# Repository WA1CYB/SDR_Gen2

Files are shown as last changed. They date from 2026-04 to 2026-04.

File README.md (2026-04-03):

# SDR\_Gen2

Prototype SDR for GOLF and FOX plus

Features:

**2 Channel Receiver**

&nbsp;	Common Input

&nbsp;	Alternative Separate Inputs

3 Selectable Input Filters

&nbsp;	VHF (2 mtrs to 500 MHz)

&nbsp;	S Band

&nbsp;	C Band

Std Mini-Circuits  Filters

&nbsp;	Substitutions available

**2 Channel Transmitter**

&nbsp;	Common Output

&nbsp;	Alternative Separate Outputs

2 Selectable Output Filters

&nbsp;	VHF (2 mtrs to 1296 MHz)

&nbsp;	S/C Band

Std Mini-Circuits  Filters

&nbsp;	Substitutions available

Output Power(s)

&nbsp;	½ to 1 watt (2 mtrs to 2700 MHz)

&nbsp;	~18 dBm (2 mtrs to 6000 MHz)

Experimental X Band Output

&nbsp;  ~ 5 dBm power output

&nbsp;

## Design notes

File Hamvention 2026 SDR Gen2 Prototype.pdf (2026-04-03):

# SDR gen2 Prototype GEN2

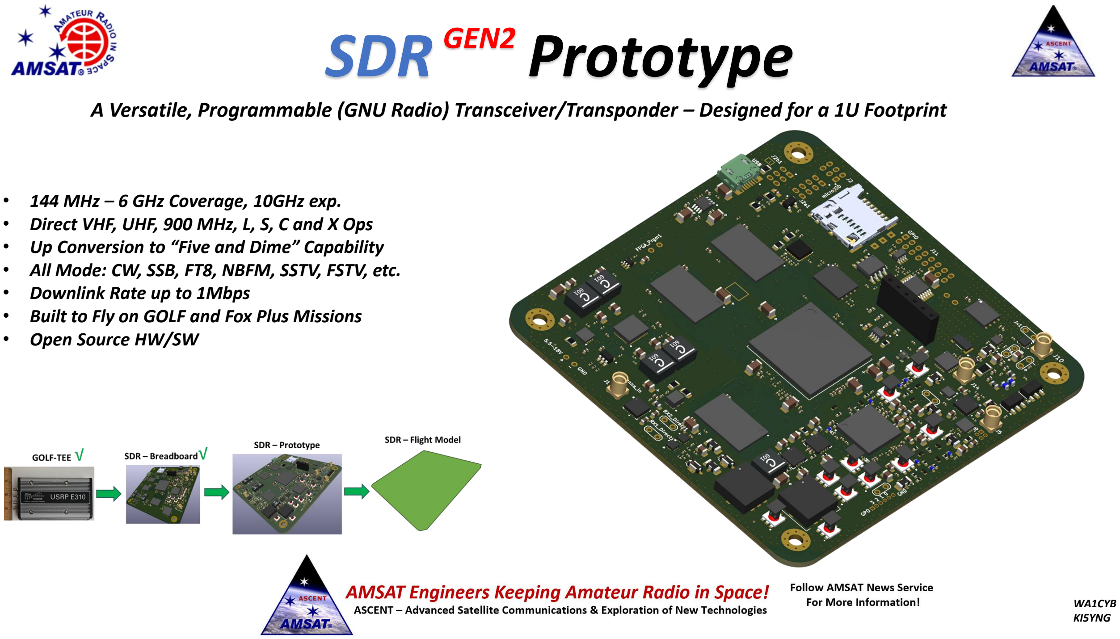
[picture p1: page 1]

- 144 MHz – 6 GHz Coverage, 10GHz exp.
- Direct VHF, UHF, 900 MHz, L, S, C and X Ops
- Up Conversion to “Five and Dime” Capability
- All Mode: CW, SSB, FT8, NBFM, SSTV, FSTV, etc.
- Downlink Rate up to 1Mbps
- Built to Fly on GOLF and Fox Plus Missions
- Open Source HW/SW

A Versatile, Programmable (GNU Radio) Transceiver/Transponder – Designed for a 1U Footprint

WA1CYB
KI5YNG

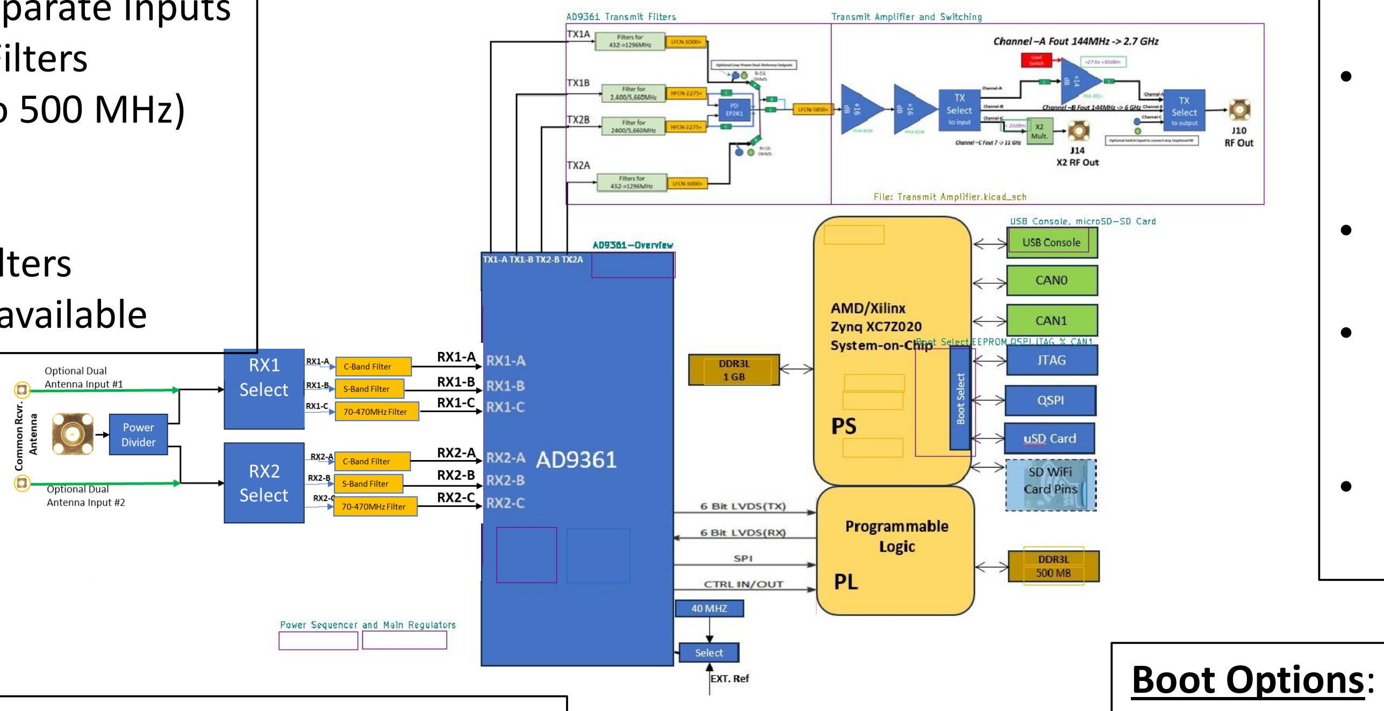
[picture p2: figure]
Boot Options:

Xilinx Zynq 7020 FPGA
- 1GB System RAM
- Linux
- ½ GB Programmable Logic Available for interfaces
- UHD/ IIO Drivers planned
- Dual CAN Bus Interface
- Serial/USB Interface
- JTAG
- Micro SD Card (64GB)
- QSPI Flash (128Mbit, 16 MByte) SPI Serial
- EEPROM (256K (32 kByte) I2C CMOS Serial)

### 2 Channel Transmitter

- Common Output
- Alternative Separate Outputs
- 2 Selectable Output Filters
- VHF (2 mtrs to 1296 MHz)
- S/C Band
- Std Mini-Circuits Filters
- Substitutions available
- Output Power(s)
- ½ to 1 watt (2 mtrs to 2700 MHz)
- ~18 dBm (2 mtrs to 6000 MHz)
- Experimental X Band Output
- ~ 5 dBm power output

Other: Optional Clk. Ref, Load Switch for PA, GPIO

### 2 Channel Receiver

- Common Input
- Alternative Separate Inputs
- 3 Selectable Input Filters
- VHF (2 mtrs to 500 MHz)
- S Band
- C Band
- Std Mini-Circuits Filters
- Substitutions available

# SDR gen2 Prototype GEN2

# Backup

# SDR Transponder/Transceiver for

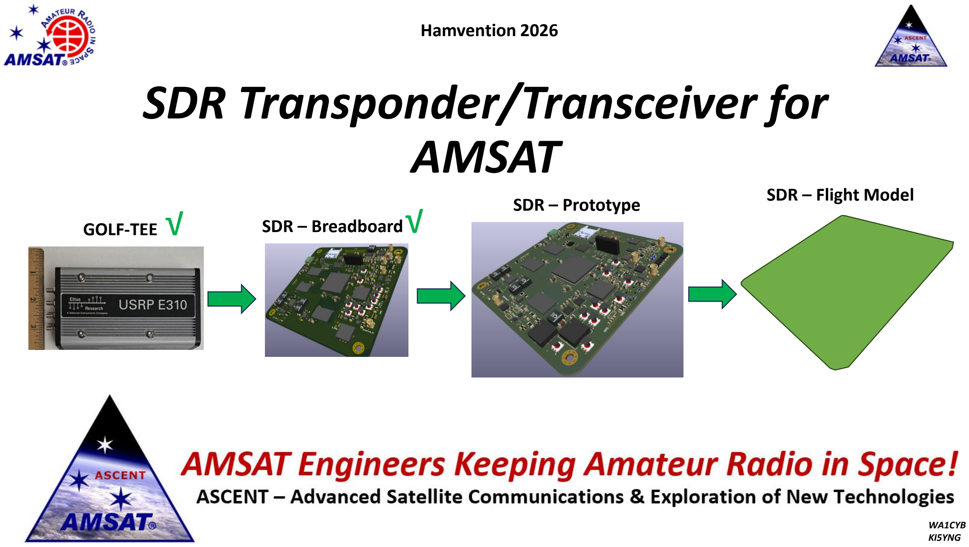
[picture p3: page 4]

# AMSAT

Hamvention 2026

GOLF-TEE | SDR – Breadboard
SDR – Prototype | SDR – Flight Model
√ | √

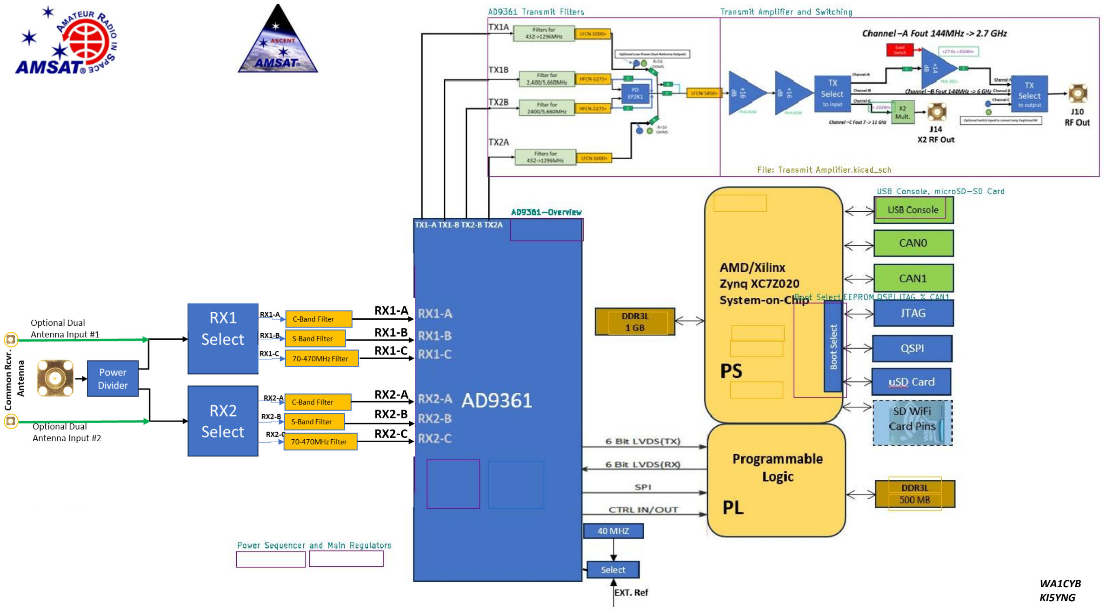
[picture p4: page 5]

# SDR gen2 Prototype GEN2

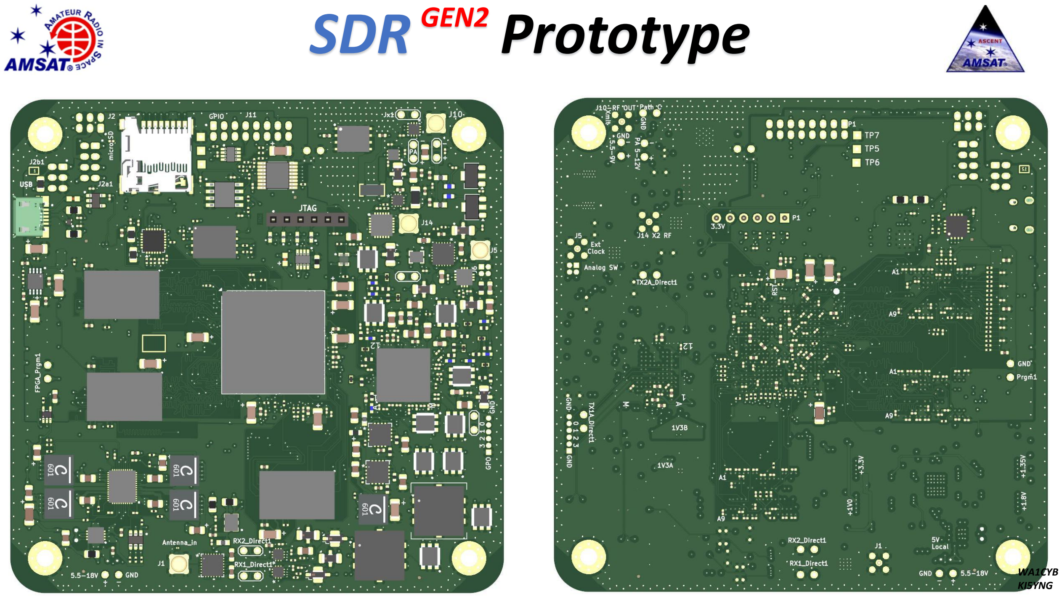
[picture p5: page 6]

# SDR gen2 Prototype GEN2

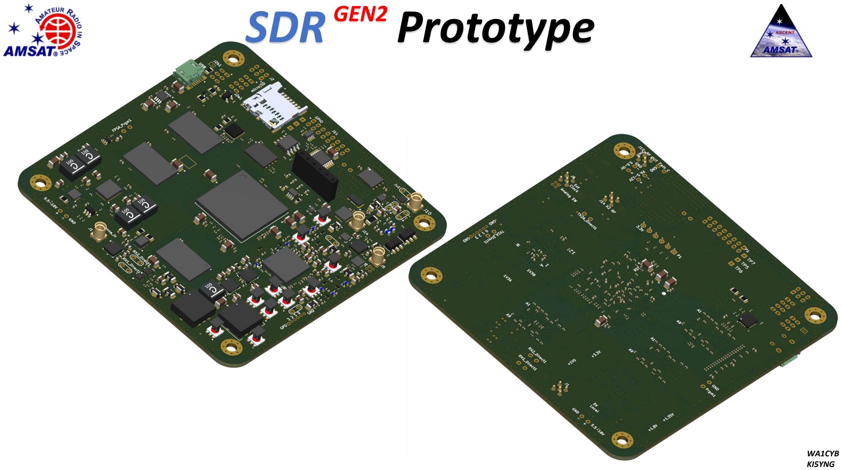
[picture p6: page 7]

# SDR gen2 Prototype GEN2

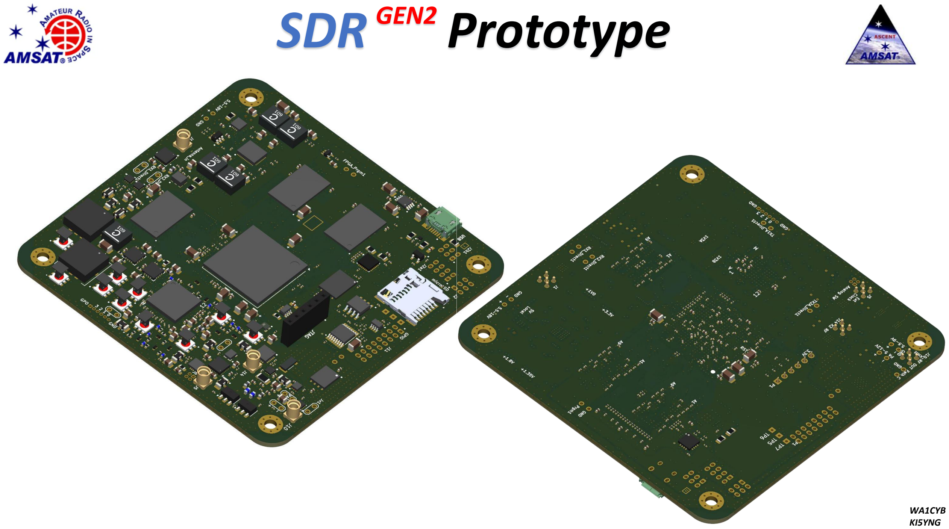
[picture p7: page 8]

# SDR gen2 Prototype GEN2

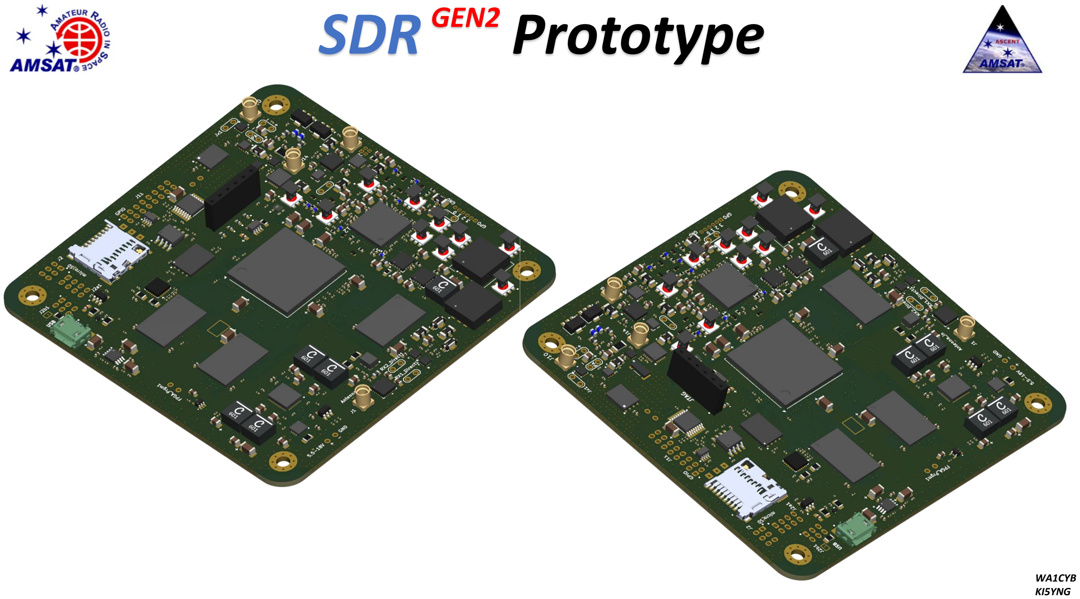
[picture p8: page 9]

- Replaces the Ettus E310 (123.9 x 68.2 x 26.4 mm) with a custom SDR card (92 x 92 x7.5 mm + Heat Sink)
- Provides 1 watt output (goal)
- Open source (It will be / is on GitHub) for now it will be in: https://github.com/WA1CYB/SDR_Gen2
- KiCad 9 schematic and layout used. Re-use and modifications encouraged

WA1CYB 10

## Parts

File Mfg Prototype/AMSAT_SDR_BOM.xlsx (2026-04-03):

Item # | Designator | Qty | Manufacturer | Mfg Part # | Description / Value | Vendor Part # (JLCPCB ) | Alternate Vendor Part # (Digikey Part #) | Package/Footprint | Mounting Type | non SMD part | DNP | Note | Datasheet
1 | C1,C2,C3,C5,C7,C98,C126,C141,C174,C246,C250,C253,C270,C271,C273 | 15 | Venkel | C0201Y5V6R3-104ZNP | 0.1uf | C3846467 |  | 201 | SMD
2 | C4,C10,C17,C19,C69,C70,C76,C77,C100,C101,C104,C106,C110,C111,C196,C269,C359,C364,C365,C366,C367 | 21 | Taiyo Yuden | TMK063B7103KP-F | 0.01uf | C2168155 |  | 201 | SMD
3 | C6 | 1 | Samsung Electro-Mechanics | CL10B104KA8NNNC | 100nF 25V X7R ±10% MLCC | C1590 |  | 603 | SMD
4 | C8,C86,C242,C272 | 4 | FH (Guangdong Fenghua Advanced Tech) | 0402B103K500NT | 10nF 50V X7R ±10% MLCC | C1524 |  | 402 | SMD
5 | C9 | 1 | FH (Guangdong Fenghua Advanced Tech) | 0805F474M500NT | 470nF 50V Y5V MLCC | C1778 |  | 402 | SMD
6 | C14,C15 | 2 | FH (Guangdong Fenghua Advanced Tech) | 0402CG180J500NT | 18pF 50V C0G ±5% MLCC | C1549 |  | 603 | SMD
7 | C16 | 1 | Samsung Electro-Mechanics | CL21A475KAQNNNE | 4.7uf | C1779 |  | 805 | SMD
8 | C18,C73,C163,C164,C168,C171,C172,C173,C175,C185,C191,C192,C193,C194,C206,C210,C214,C218,C222,C223,C234,C241,C252,C265,C274,C275,C277,C282,C283,C302,C303,C322,C353 | 33 | KEMET | C0402C475M9PAC7411 | 4.7uf | C2231296 |  | 402 | SMD
9 | C20,C67,C90,C95,C96,C97,C102,C103,C105,C109,C118,C125,C156,C159,C358 | 15 | Murata Electronics | GRM155B31A105KE15D | 1uf | C162154 |  | 402 | SMD
10 | C21,C157,C160,C209 | 4 | Walsin Tech Corp | 0201B101K250CT | 100pf | C908474 |  | 201 | SMD
11 | C22,C71,C72,C74,C75,C88,C89,C93,C94,C99,C127,C133,C139,C148,C368 | 15 | Samsung Electro-Mechanics | CL21A106KAENRBE | 10uf | C307517 |  | 805 | SMD
12 | C23,C155 | 2 |  |  | 100pf |  |  | 402
13 | C65 | 1 | IHHEC(HOLY STONE ENTERPRISE CO., LTD) | C0805X105K025TX | 1uf | C2940738 |  | 805 | SMD
14 | C66,C68,C78,C79,C80,C81,C195 | 7 | SANYEAR | C0805X5R226K100NT | 22uf | C968780 |  | 805 | SMD
15 | C82,C161,C162,C169,C199,C201,C217,C221,C257 | 9 | TDK | C3216X5R1A107M160AC | 100uf | C2167823 |  | 1206 | SMD
16 | C107,C108,C132,C136,C140,C149,C267,C137 | 8 | YAGEO | AC0201KRX7R9BB102 | 0.001uf | C3843341 |  | 201 | SMD
17 | C154,C158 | 2 | Murata Electronics | GRM0335C1H180JA01D | 18pf | C85892 |  | 201 | SMD
18 | C128,C129,C130,C131,C144,C145,C146,C147 | 8 | YAGEO | CC0201FRNPO8BN120 | 12pf | C541254 |  | 201 | SMD
19 | C134,C138,C143,C150 | 4 | Samsung Electro-Mechanics | CL10C470JB8NNNC | 47pF 50V C0G ±5% MLCC | C1671 |  | 603 | SMD
20 | C142 | 1 | SANYEAR | C0805X7R102J500NT | 0.001uf 50V | C2835539 |  | 805 | SMD
21 | C165,C166 | 2 | SANYEAR | C0402X5R474K250NT | 0.47uf | C2835544 |  | 402 | SMD
22 | C167,C170,C233,C259 | 4 | Murata Electronics | GRT31CR61A476ME13L | 47uf | C2167841 |  | 1206 | SMD
23 | C176,C177,C178,C179,C180,C181,C182,C183,C184,C197,C198,C200,C204,C205,C207,C211,C216,C219,C224,C225,C226,C227,C229,C235,C236,C237,C240,C243,C251,C254,C255,C256,C263,C264,C278,C279,C280,C281,C284,C285,C304,C305,C332,C341,C342,C343,C344,C345,C346,C347,C348,C349,C350,C351,C352,C354,C355,C356,C357 | 59 | Taiyo Yuden | LMK063BBJ474MPLF | 0.47uf | C2169172 |  | 201 | SMD
24 | C186,C187,C188,C189,C202,C203,C212,C220,C230,C231,C232,C260,C261,C262,C286,C287,C288,C289,C290,C291,C292,C293,C294,C295,C296,C297,C298,C299,C300,C301,C306,C307,C308,C309,C310,C311,C312,C313,C314,C315,C316,C317,C318,C319,C320,C321,C323,C324,C325,C326,C327,C328,C329,C330,C331,C333,C334,C335,C336,C337,C338,C339,C340,C360,C361,C363 | 66 | PSA(Prosperity Dielectrics) | FN03B473K6R3PLG | 0.047uf | C565524 |  | 201 | SMD
25 | C213 | 1 | Kyocera | F950G337KAAAQ2 | 330uf | C1964682 |  | 1206 | SMD
26 | C215,C268 | 2 | Taiyo Yuden | JDK105BJ106MV-FD | 10uf | C841046 |  | 402 | SMD
27 | C228 | 1 | Murata Electronics | GRT155R6YA224KE01D | 0.22uf | C180396 |  | 402 | SMD
28 | C238 | 1 | Taiyo Yuden | EMK063B7103KP-F | 0.01uf 10V | C2174059 |  | 201 | SMD
29 | C239,C258 | 2 | Vishay Intertech | VJ0201G223KXYCW1BC | 0.22uf | C2197009 |  | 201 | SMD
30 | C244,C247,C276 | 3 | SANYEAR | C1206X6S226M160NT | 22uf | C2844312 |  | 1206 | SMD
31 | C245 | 1 | YAGEO | CC1206KRX7R0BB472 | 100V 4.7nF X7R ±10% MLCC | C577234 |  | 1206 | SMD |  |  | OK to Substitute with: 1206B472K101CT
32 | C248,C249 | 2 | Walsin Tech Corp | MT03N470J500CT | 47pf | C2918569 |  | 201 | SMD
33 | CR1 | 1 | onsemi | ESD8472MUT5G | ESD8472MUT5G | C2830297 | ESD8472MUT5GOSTR-ND | X3DFN2_ONS | SMD |  |  |  | ESD8472MUT5G
34 | FL1 | 1 | Coilcraft | WA8514-AE | 5.6uh wideband 3GHz RF Choke | C22386157 |  | WA8514AE | SMD |  |  |  | https://www.coilcraft.com/getmedia/4491c14d-61bb-4c33-922c-9709ccb7b4e5/wa8514.pdf
35 | IC1 | 1 | Analog Devices Inc. | LT7200SAV#TRPBF | LT7200SAV#TRPBF |  | 505-LT7200SAV#TRPBFTR-ND | LT7200SAVTRPBF | SMD |  |  |  | https://www.analog.com/media/en/technical-documentation/data-sheets/lt7200s.pdf
36 | IC2 | 1 | Analog Devices Inc. | ADG772BCPZ-1REEL | digital ctl. Analog Switch | C143887 | 505-ADG772BCPZ-1REELTR-ND | QFN50P300X300X80-13N-D | QFN LFCSP | x |  | 12 pin package | https://www.analog.com/media/en/technical-documentation/data-sheets/ADG772.pdf
37 | IC3 | 1 | Mini-Circuits | CY2-143+ | X2 Freq. Multiplier CY2-143+ |  |  | DG1847 4x4mm | QFN | x |  |  | https://www.minicircuits.com/pdfs/CY2-143+.pdf
38 | IC4 | 1 | TI | TPS22810DRVT | 2Amp Load Switch | C2653758 | 296-46947-1-ND - Cut Tape (CT) | DRV0006A , WSON 2×2mm | WSON | x |  |  | http://www.ti.com/lit/gpn/tps22810-q1
39 | IC5,IC6,IC7 | 3 | Micron Technology Inc. | MT41K256M16TW-107:P | MT41K256M16HA-107E | C253882 | 557-1792-ND | BGA96C80P9X16_900X1400X120 | BGA | x |  |  | https://media-www.micron.com/-/media/client/global/documents/products/data-sheet/dram/ddr3/8gb_ddr3l.pdf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
40 | IC8 | 1 | Microchip Technology | 24AA256-I/SN | 24AA256-I_SN | C152169 | 24AA256-I/SN-ND | SOIC127P600X175-8N | SOIC127 | x |  |  | http://ww1.microchip.com/downloads/en/DeviceDoc/20001203U.pdf
41 | IC9 | 1 | Mini-Circuits | PHA-202+ | Amplifier, PHA-202+ | C5845121 |  | SON127P600X490X100-9N-D | SON127 | x |  |  | https://www.minicircuits.com/WebStore/dashboard.html?model=PHA-202%2B
42 | J1,J5, J10,J14 | 4 | Molex | 734151471 | MMCX Coax Connector | C588477 | WM5557-ND | MMCX_Molex_73415-1471_Vertical | Thru Hole | x
43 | J12 | 1 | Amphenol ICC (FCI) | 10103594-0001LF | 10103594-0001LF | C428495 | 609-4050-2-ND | USB_Micro_B_Female_10103594-0001LF | Thru Hole | x |  |  | https://cdn.amphenol-icc.com/media/wysiwyg/files/drawing/10103594.pdf
44 | J13 | 1 | Molex | 503398-1892 | Micro SD Holder | C428492 | WM11190TR-ND | MOLEX_503398-1892 | SMD
45 | J15 | 1 | Sullins Connector Solutions | PPTC061LFBN-RC | JTAG Conn_01x06_Pin | C5272871 | S7004-ND | PinSocket_1x06_P2.54mm_Vertical | Thru Hole | x
46 | L1,L2,L3,L4,L12,L14,L16,L18 | 8 | TDK Corporation | MLJ1005WR33JT000 | 330nh MLJ1005WR33JT000 | C2043066 | 445-180955-2-ND | IND_MLJ1005WR33JT000 | SMD
47 | L5,L6,L7,L8,L9 | 5 | CoilCraft | XGL5030-601MEC | 0.6uh XEL5030-601ME | C3911471 | 2457-XGL5030-601MEC-ND | IND_XEL5030_3.2_COC | SMD
48 | L10,L11,L26 | 3 | Murata Electronics | BLM18AG601SN1D | BLM18AG601SN1D 0603 | C19330 | 490-1014-2-ND | IND_BLM18_0603_MUR | SMD
49 | L13,L15,L17,L19,L20,L21,L27,L28 | 8 | Murata Electronics | LQW15AN33NJ00D | 33nh LQW15AN33NJ00D | C192564 |  | LQW15CNR20J00B | SMD
50 | L22,L29 | 2 | Murata Electronics | BLM18HE152SN1D | Ferrite BLM18HE152SN1 | C82155 | 490-5216-2-ND | IND_BLM18_0603_MUR | SMD
51 | L23,L30 | 2 | Murata Electronics | LQM18PH1R0MFRL | 330 nh 0603 | C1858042 |  | LQM18PH1R0MFRL | SMD
52 | L24,L25 | 2 | Murata Electronics | BLM18PG-121SND | BLM18PG-121SND | C14709 |  | 603 | SMD
53 | R1,R29,R31,R42,R51,R61,R64,R65 | 8 | UNI-ROYAL(Uniroyal Elec) | 0402WGF4700TCE | 470Ω 50V ±1% | C25117 |  | 402 | SMD
54 | R2,R30,R34,R45,R62,R63,R66,R70 | 8 | UNI-ROYAL | 0402WGF1001TCE | 1kΩ 50V ±1% ±100ppm/℃ | C11702 |  | 402 | SMD
55 | R3,R5,R156 | 3 | TE Connectivity | CPF0805B499RE1 | 499 | C1695674 |  | 805 | SMD
56 | R6,R7,R8,R9,R10,R25,R57,R87 | 8 | RALEC | RTT012052FTH | 20.5kΩ 25V ±1% ±200ppm/℃ | C166301 |  | 201 | SMD
57 | R11,R12,R13,R44,R80,R99,R100,R101,R102,R103,R105,R134,R141,R185 | 14 | YAGEO | RC0201FR-074K7L | 4.7kΩ 50mW ±1% Resistor | C138135 |  | 201 | SMD
58 | R14,R15,R16 | 3 | YAGEO | RC0201FR-073KL | 3k ±1% Resistor | C142016 |  | 201 | SMD
59 | R17,R21 | 2 | UNI-ROYAL | 0402WGF0000TCE | 0 ohms | C17168 |  | 402 | SMD
60 | R19,R20,R35,R36,R37,R46,R160 | 7 | UNI-ROYAL(Uniroyal Elec) | 0201WMJ1003TEE | 100k | C2691500 |  | 201 | SMD
61 | R26,R27,R28,R43,R54,R76,R77,R78,R79,R81,R82,R83,R84,R85,R86,R88,R89,R104,R130,R147,R164,R165,R166,R167,R168,R169,R170,R171,R172,R173,R174,R175,R176,R177,R178,R179,R180,R181,R182 | 39 | YAGEO | RC0201FR-0716R9L | 16.9 | C474547 |  | 201 | SMD
62 | R32 | 1 | UNI-ROYAL(Uniroyal Elec) | HQ05W3J0000T5E | 0 ohms | C2792442 |  | 805 | SMD
63 | R38 | 1 | PANASONIC | ERJ-U01F5622C | 56.2k | C4114717 |  | 201 | SMD
64 | R39,R40,R41,R48,R50,R68,R69,R72,R73,R74,R75,R91,R92,R152,R154 | 15 | PANASONIC | ERJ-1GEJ103C | 10k, ±1% | C2097746 |  | 201 | SMD
65 | R47 | 1 | RALEC | RTT011652FTH | 16.5kΩ ±1% 25V Resistor | C166335 |  | 201 | SMD
66 | R49 | 1 | UNI-ROYAL(Uniroyal Elec) | 0201WMF2612TEE | 26.1k | C423632 |  | 201 | SMD
67 | R52,R67,R107,R108,R109,R138,R151,R183,R184,C112,C113,C114,C115,C116,C117,C119,C120,C121,C122,C123,C124 | 21 | UNI-ROYAL(Uniroyal Elec) | PF01WMJ0000TEE | 0 ohms | C2784589 |  | 201 | SMD
68 | R53 | 1 | Venkel | CR0201-20W-1432FT | 14.3k | C4121995 |  | 201 | SMD
69 | R55,R56 | 2 | YAGEO | AC0201FR-071R05L | 1.05 | C4272938 |  | 201 | SMD
70 | R59,R60,R95,R96,R110,R111,R112,R113,R114,R115,R116,R117,R118,R119,R120,R121,R122,R123,R124,R125,R126,R127,R128,R129,R131,R132,R133,R139,R140,R163 | 30 | SEI(Stackpole Elec) | RNCF0201DTC49R9 | 49.9 | C2488211 |  | 201 | SMD
71 | R90 | 1 | UNI-ROYAL | 0603WAF2612T5E | 26.1kΩ 75V ±1% Resistor | C23356 |  | 603 | SMD
72 | R93,R97,R142 | 3 | UNI-ROYAL(Uniroyal Elec) | PF01WMF2400TEE | 240 | C2784587 |  | 201 | SMD |  |  | OK to Substitute with: RC0201FR-07240RL
73 | R135,R136 | 2 |  | 0201WMF787JTEE | 78.7 |  |  | 201 | SMD
74 | R137 | 1 | UNI-ROYAL | 1206W4F2201T5E | 2.2kΩ 0.25W ±1% Resistor | C17948 |  | 1206 | SMD
75 | R161 | 1 | Vishay Intertech | TNPW02011K10BEED | 1.1k | C3946172 |  | 201 | SMD
76 | R148 | 1 | Vishay Intertech | CRCW02011M05FNED | 1.05meg | C3916432 |  | 201 | SMD |  |  | Resistor can be 1 meg for a substitute
77 | R149,R150 | 2 | YAGEO | RT0805DRE0727R4L | 27.4 | C868682 |  | 805 | SMD
78 | R153,R155 | 2 | SEI(Stackpole Elec) | RMCF0201FT330R | 330 | C2479078 |  | 201 | SMD
79 | R157 | 1 | FH (Guangdong Fenghua Advanced Tech) | RS-05K2052FT | 20.5k | C322346 |  | 805 | SMD
80 | R159,R189,R145,R146 | 4 | UNI-ROYAL(Uniroyal Elec) | 0201WMD1202TEE | 12k | C2766436 |  | 201 | SMD
81 | R186 | 1 | Vishay Intertech | RCC0805100RFKEA | 100 | C1859587 |  | 805 | SMD
82 | R187 | 1 | Viking Tech | AR05DTBW1500 | 150 | C2984396 |  | 805 | SMD
83 | R188 | 1 |  | RC0201JR-0722RL | 22 |  |  | 201 | SMD |  |  | OK to Substitute with: RC0201JR-0722RL
84 | RV1,RV2,RV3,RV4 | 4 | BOURNS | CG0402MLU-3.3G | ESD Suppressor CG0402MLU-3.3G | C2655393 |  | VARC1005X41N | SMD |  |  |  | https://www.bourns.com/docs/Product-Datasheets/MLU.pdf
85 | T2,T3,T4,T5,T6,T7,T8,T9,T10,T11 | 10 | Mini-Circuits | TCM1-63AX+ | TCM1-63AX+ | C494678 | 3157-TCM1-63AX+TR-ND | DB1627_MNC, SMD-6P | SMD |  |  |  | TCM1-63AX+
86 | U1,U10,U11,U12 | 4 | SKYWORKS | SKY13588-460LF | SP3T Switch, SKY13588-460LF | C2151906 |  | QFN12 | QFN | x |  |  | SKY13588-460LF
87 | U2,U39 | 2 | Analog Devices | MAX3051EKA-T | CAN, MAX3051 | C112005 | MAX3051EKA+TTR-ND | MAX3051EKA-T | SMD |  |  |  | http://datasheets.maximintegrated.com/en/ds/MAX3051.pdf
88 | U3,U24 | 2 | Mini-Circuits | EP2K1+ | Power Divider, EP2K1+ | C2683436 | 3157-EP2K1+CT-ND - Cut Tape (CT) | DG1847_MNC-L,QFN-24-EP(4x4) | QFN | x |  |  | EP2K1+
89 | U4,U9 | 2 | Mini-Circuits | RLP-470+ | Filter, RLP-470+ | C3155764 |  | GP731, SMD-8P,8.9x8.9mm | SMD
90 | U5,U8 | 2 | Mini-Circuits | BFCN-5750+ | Filter,BFCN-5750+ | C4989833 |  | FV1206-4, SMD3216-4P | SMD
91 | U6,U7 | 2 | Mini-Circuits | BFCN-2360+ | Filter,BFCN-2360+ | C4989831 | 3157-BFCN-2360+CT-ND - Cut Tape (CT) | FV1206, | SMD
92 | U13,U32 | 2 | Mini-Circuits | LFCN-5850+ | Filter,LFCN-5850+ | C2683450 |  | FV1206, SMD-4P,3.2x1.6mm | SMD |  |  |  | https://www.minicircuits.com/pdfs/LFCN-5850+.pdf
93 | U15 | 1 | Texas Instruments | TXS02612RTWR | SDIO PORT EXPANDER | C140276 |  | QFN:WQFN-24-1EP | QFN | x |  |  | https://www.ti.com/lit/gpn/TXS02612
94 | U16 | 1 | Wuxi I-core Elec | 74LVC1G07 | Open Drain SOT-353 Buffer | C5138996 |  | SOT-353 | SOT | x |  |  | https://www.ti.com/lit/ds/symlink/sn74lvc1g07.pdf
95 | U17 | 1 | Texas Instruments | CD4043BPWR | CD 4043 tri state latch | C2652970 |  | SOP65P640X120-16N | SOP | x |  |  | https://www.ti.com/lit/gpn/cd4043b
96 | U18,U20 | 2 | Analog Devices | ADP1754ACPZ-1.3-R7 | LDO 1.3V regulator | C3747719 |  | LFCSP-16(4x4) | SMD |  |  |  | https://www.analog.com/media/en/technical-documentation/data-sheets/ADP1754_1755.pdf
97 | U19,U23 | 2 | Mini-Circuits | LFCN-1000+ | Filter,LFCN-1000+ | C879868 |  | FV1206 SMD-4P,3.2x1.6mm | SMD
98 | U21 | 1 | Texas Instruments | LM3880MF-1AC/NOPB | LM3880 | C471861 | LM3880MF-1AC/NOPBTR-ND | TO_SOT_SMD:SOT-23-6 | SMD |  |  |  | http://www.ti.com/lit/ds/symlink/lm3880.pdf
99 | U22 | 1 | Analog Devices | ADP7104ACPZ-5.0-R7 | ADP7104ACPZ-5.0-R7 | C207497 | 505-ADP7104ACPZ-5.0-R7TR-ND | CP_8_5_ADI | SMD |  |  |  | ADP7104ACPZ-2.5-R7
100 | U25 | 1 | Analog Devices | AD9361BBCZ | AD9361BBCZ | C515884 |  | BC_144_7_ADI | BGA | x |  |  | AD9361BBCZ
101 | U28,U30 | 2 | Mini-Circuits | HFCN-2275+ | Filter, HFCN-2275+ | C4989532 | 3157-HFCN-2275+CT-ND - Cut Tape (CT) | FV1206 | SMD
102 | U37,U45 | 2 | Mini-Circuits | PHA-83W+ | Amplifier, PHA-83W+ | C20231740 | 3157-PHA-83W+CT-ND - Cut Tape (CT) | SOT-89-3 | SOT | x
103 | U38 | 1 | XILINX | XC7Z020-1CLG484C | XC7Z020-1CLG484C | C1519066 |  | Xilinx_CLG484_CLG485 | BGA | x |  |  | XC7Z020-1CLG484C
104 | U40 | 1 | ROHM Semicon | BD3539FVM-TR | BD3539FVM-TR | C213437 | BD3539FVM-TR-ND | MSOP8_ROM | SMD |  |  |  | BD3539FVM-TR
105 | U41 | 1 | Texas Instruments | TPD2EUSB30DRTR | TPD2EUSB30 | C97502 | 296-25509-2-ND | TO_SOT_SMD:Texas_DRT-3 | SMD |  |  |  | http://www.ti.com/lit/ds/symlink/tpd2eusb30a.pdf
106 | U42 | 1 | FTDI | FT230XQ-R | FT230XQ | C128629 | 768-1130-2-ND | QFN-16-1EP_4x4mm_P0.65mm_EP2.1x2.1mm | QFN | x |  |  | https://www.ftdichip.com/Support/Documents/DataSheets/ICs/DS_FT230X.pdf
107 | U43 | 1 | Texas Instruments | LP5907MFX-3.3/NOPB | LP5907MFX-3.3 | C80670 | 296-38557-2-ND | Package_TO_SOT_SMD:SOT-23-5 | SMD |  |  |  | http://www.ti.com/lit/ds/symlink/lp5907.pdf
108 | U44 | 1 | Winbond | W25Q128JVEIQ | W25Q128JVEIQ | C401662 | W25Q128JVEIQ-ND | WSON_128JVEIQ_WIN | BGA | x |  |  | http://www.winbond.com/resource-files/w25q128jv_dtr%20revc%2003272018%20plus.pdf
109 | Y1 | 1 | Epson | TG2520SMN 40.0000M-ECGNNM3 | 40 MHz Crystal | C1512882 | 114-TG2520SMN40.0000M-ECGNNM3TR-ND | TG2520SMN400000MECGNNM0 | SMD |  |  |  | https://www.mouser.cn/datasheet/2/137/TG2520SMN_en-2584158.pdf
110 | Y2 | 1 | KYOCERA AVX | KC2016Z33.3330C1KX00 | 33.3330 MHz Crystal | C21266789 | 478-KC2016Z33.3330C1KX00TR-ND | KC2016Z333330C1KX00 | SMD |  |  |  | https://ele.kyocera.com/assets/products/crystal-device/clock_z_x_e.pdf
111 | Y3 | 1 | ECS Inc. | ETXO-H33CL-100.000 | 100 MHz Crystal | C2636526 | XC2134-ND | ETXOH33CL100000 | SMD |  |  |  | http://www.ecsxtal.com/store/pdf/ETXO-H.pdf
 |  | 585 | Parts
 | Do Not Populate (DNP) Part Designator
1 | C11,C12 | 0 | DNP |  | DNP |  |  | 603 |  |  | X
2 | C135 | 0 | DNP |  | 0 pf DNP |  |  | 603 |  |  | X
3 | C190,C208,C266,C362 | 0 | DNP |  | DNP |  |  | 201 |  |  | X
4 | J2 | 0 | DNP |  | Test Point |  |  | DF11-6DP-2DSA_2x03_P2.00mm |  |  | X
5 | J2a1 | 0 | DNP |  | Test Point |  |  | 2x04_P2.00mm |  |  | X
6 | J2b1 | 0 | DNP |  | Test Point |  |  | 2x04_P2.00mm |  |  | X
7 | J3 | 0 | DNP |  | Test Point |  |  | 1.27mm:PinSocket_1x06_P1.27mm |  |  | X
8 | J6 | 0 | DNP |  | Test Point |  |  | 1.27mm:PinSocket_2x02_P1.27 |  |  | X
9 | J11 | 0 | DNP |  | Test Point |  |  | DF11-16DP-2DSA_2x08 |  |  | X
10 | Jx1 | 0 | DNP |  | Path C |  |  | TestPoints |  |  | X
11 | R4 | 0 | DNP |  | DNP 20.5k |  |  | 805 |  |  | X
12 | R18,R22 | 0 | DNP |  | DNP |  |  | 402 |  |  | X
13 | R23,R24,R106 | 0 | DNP |  | DNP |  |  | 201 |  |  | X
14 | R33 | 0 | DNP |  | 10k-DNP |  |  | 201 |  |  | X
15 | R58 | 0 | DNP |  | DNP |  |  | 603 |  |  | X
16 | R71 | 0 | DNP |  | DNP 0 ohms |  |  | 603 |  |  | X
17 | R94,R98 | 0 | DNP |  | DNP - 4.7K |  |  | 201 |  |  | X
18 | TP5,TP6, TP7 | 0 | DNP |  | TestPoint |  |  | TestPoint:1.5x1.5mm_Drill0.7mm |  |  | X
 | DNP Unique Parts | 18 | 28
 |  |  |  |  |  |  |  |  |  |  |  |  |  |  | Unique Parts (92 SMD, 3 through hole, 16 other)
 |  |  |  |  |  |  |  |  |  |  |  |  |  |  | Type | total #
 |  |  |  |  |  |  |  |  |  |  |  |  |  | QFN | 6 | 10
 |  |  |  |  |  |  |  |  |  |  |  |  |  | BGA | 4 | 6
 |  |  |  |  |  |  |  |  |  |  |  |  |  | WSON | 1 | 1
 |  |  |  |  |  |  |  |  |  |  |  |  |  | SOIC127 | 1 | 1
 |  |  |  |  |  |  |  |  |  |  |  |  |  | SON127 | 1 | 1
 |  |  |  |  |  |  |  |  |  |  |  |  |  | SOT | 2 | 3
 |  |  |  |  |  |  |  |  |  |  |  |  |  | SOP | 1 | 1
 |  |  |  |  |  |  |  |  |  |  |  |  |  |  | 16 | 23
 |  |  |  |  |  |  |  |  |  |  |  |  |  | Thru Hole Parts | 3 | 5
 |  |  |  |  |  |  |  |  |  |  |  |  |  | SMD | 92 | 557
 |  |  |  |  |  |  |  |  |  |  |  |  |  | Total Number | 111 | 585
